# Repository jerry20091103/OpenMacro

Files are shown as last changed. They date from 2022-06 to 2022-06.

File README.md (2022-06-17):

# OpenMacro
A extensible macro device and password manager built with Arduino.

## About this repository

This repository contains three subprojects:
* **OpenMacro-Arduino:** A macropad program designed to be run on an Arduino Micro board.
* **OpenMacro-GUI:** A Qt application that can be used to configure an OpenMacro device. You will need the Arduino USB driver to detect the Arduino board.
* **OpenMacro-PCB:** A KiCad project that contains the layouts of a complete OpenMacro device.

Note that the OpenMacro-GUI project has a dependency to the OpenMacro-Arduino project's `Keycodes.h` and `MacroConfig.h`.

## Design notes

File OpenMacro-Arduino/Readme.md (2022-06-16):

# OpenMacro-Arduino

## Getting started with the source code
* Get the PlatfromIO extension in VScode.
* Click Open project in PlatformIO-home window and open the OpenMacro-Arduino folder.
* All libraries and tools should then automatically be installed.
* The Build and Upload button are in the bottom left corner.

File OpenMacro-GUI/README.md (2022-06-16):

# OpenMacro-GUI

## Getting started
* Open `CMakeLists.txt` in QtCreator, using the "Open Project" button. **Qt 6.3.0 is needed.**

## Debugging
* In the top menu bar, select debug options from the Debug menu.
    * These buttons are connected to slots in `App/debugmenu.h`.
    * For serial port testing, change the port name `debugPortName` defined in `App/debugmenu.cpp` to the name of the port your USB device is connected to.
* Remember that you can also see the console in Qt Creator!

## Project structure
* `App`: Contains GUI-related logic, as well as the `.ui` file that defines the UI layouts.
* `Core`: Contains OpenMacro data structures and functions.
* `commons.h`: Manages external includes.

## How to build the executable
* After building the CMake project from inside Qt Creator, you will need to add the following Qt `.dll` files to the folder containing `OpenMacro-GUI.exe`, which can be found under `Qt/6.3.0/mingw_64/bin`.
   * `libgcc_s_seh-1.dll`
   * `libstdc++-6.dll`
   * `libwinpthread-1.dll`
   * `Qt6Core.dll`
   * `Qt6Gui.dll`
   * `Qt6SerialPort.dll`
   * `Qt6Widgets.dll`
* You will also need to add `Qt/6.3.0/mingw_64/plugins/platforms` to the same folder.

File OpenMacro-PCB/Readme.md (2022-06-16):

# OpenMacro-PCB
* This folder contains Kicad 6 project files for OpenMacro.
* The electrical schematic and PCB layout Kicad files can be found here.

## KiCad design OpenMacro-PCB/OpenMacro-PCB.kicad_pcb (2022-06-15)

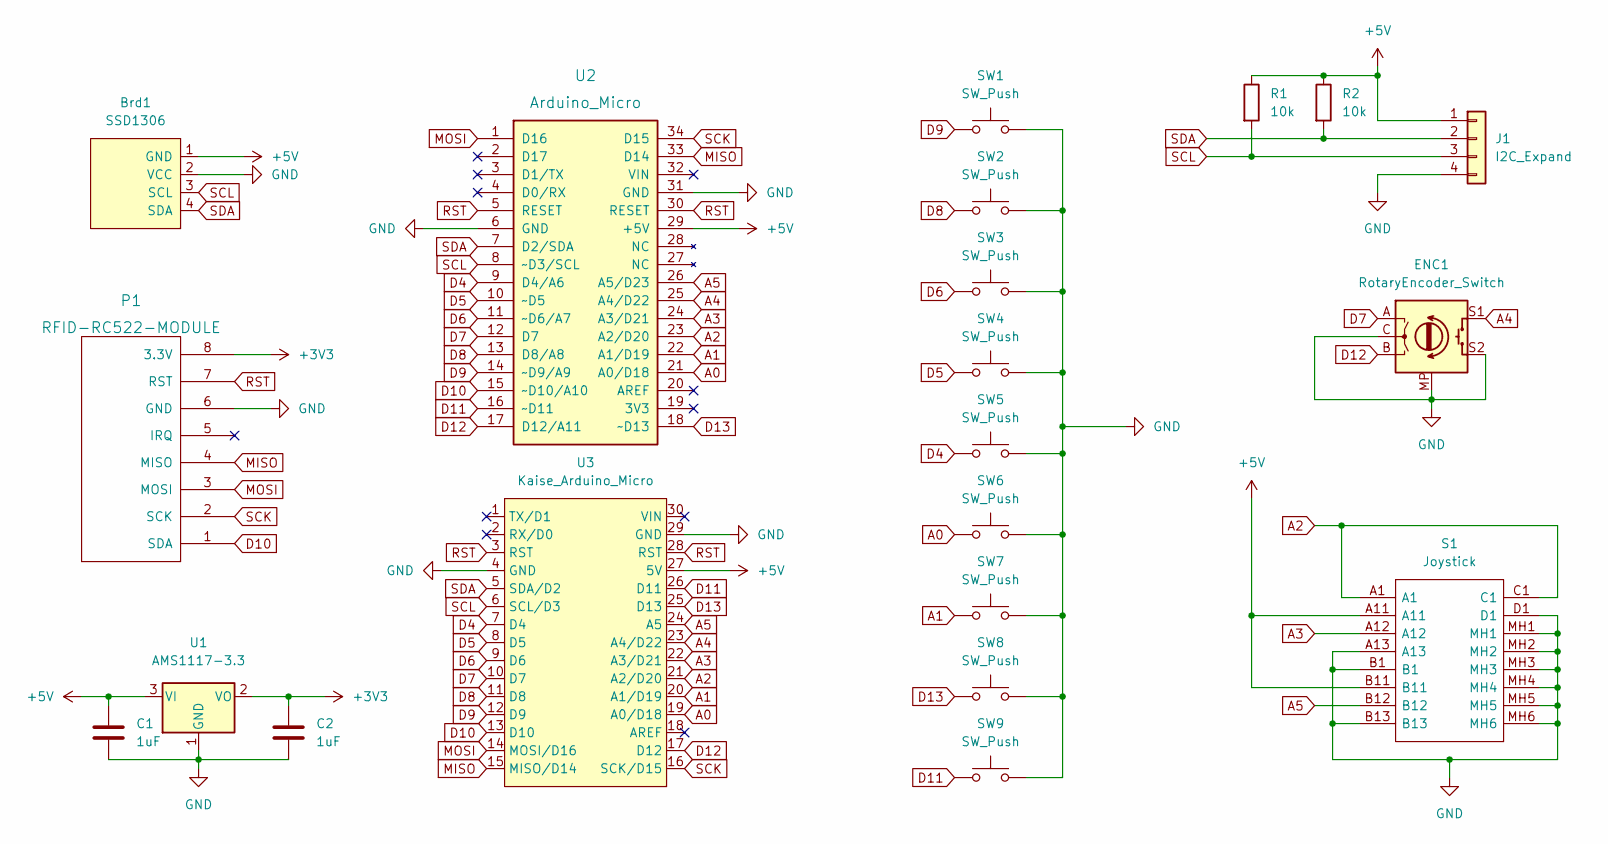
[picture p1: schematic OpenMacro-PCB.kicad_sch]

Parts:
Brd1: SSD1306; 128x64OLED
C1, C2: 1uF; C_1206_3216Metric_Pad1.33x1.80mm_HandSolder
ENC1: RotaryEncoder_Switch; RotaryEncoder_Alps_EC11E-Switch_Vertical_H20mm_CircularMoun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
J1: I2C_Expand; PinSocket_1x04_P2.54mm_Horizontal
P1: RFID-RC522-MODULE; RC-522-RFID
R1, R2: 10k; R_1206_3216Metric_Pad1.30x1.75mm_HandSolder
S1: Joystick; RKJXV122400R; Mouser Part Number 688-RKJXV122400R
SW1, SW2, SW3, SW4, SW5, SW6, SW7, SW8, SW9: SW_Push; MX-Alps-Choc-1U-NoLED
U1: AMS1117-3.3; SOT-223-3_TabPin2
U2: Arduino_Micro
U3: Kaise_Arduino_Micro

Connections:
+3V3: C2.1, P1.8 (3.3V), U1.2 (VO)
+5V: Brd1.1 (GND), C1.1, J1.1, R1.1, R2.1, S1.A11, S1.B11, U1.3 (VI), U2.29 (+5V), U3.27 (5V)
A0: SW6.1, U2.21 (A0/D18), U3.19 (A0/D18)
A1: SW7.1, U2.22 (A1/D19), U3.20 (A1/D19)
A2: S1.A1, S1.C1, U2.23 (A2/D20), U3.21 (A2/D20)
A3: S1.A12, U2.24 (A3/D21), U3.22 (A3/D21)
A4: ENC1.S1, U2.25 (A4/D22), U3.23 (A4/D22)
A5: S1.B12, U2.26 (A5/D23), U3.24 (A5)
D4: SW5.1, U2.9 (D4/A6), U3.7 (D4)
D5: SW4.1, U2.10 (~D5), U3.8 (D5)
D6: SW3.1, U2.11 (~D6/A7), U3.9 (D6)
D7: ENC1.A, U2.12 (D7), U3.10 (D7)
D8: SW2.1, U2.13 (D8/A8), U3.11 (D8)
D9: SW1.1, U2.14 (~D9/A9), U3.12 (D9)
D10: P1.1 (SDA), U2.15 (~D10/A10), U3.13 (D10)
D11: SW9.1, U2.16 (~D11), U3.26 (D11)
D12: ENC1.B, U2.17 (D12/A11), U3.17 (D12)
D13: SW8.1, U2.18 (~D13), U3.25 (D13)
GND: Brd1.2 (VCC), C1.2, C2.2, ENC1.C, ENC1.MP, ENC1.S2, J1.4, P1.6 (GND), S1.A13, S1.B1, S1.B13, S1.D1, S1.MH1, S1.MH2, S1.MH3, S1.MH4, S1.MH5, S1.MH6, SW1.2, SW2.2, SW3.2, SW4.2, SW5.2, SW6.2, SW7.2, SW8.2, SW9.2, U1.1 (GND), U2.6 (GND), U2.31 (GND), U3.4 (GND), U3.29 (GND)
MISO: P1.4 (MISO), U2.33 (D14), U3.15 (MISO/D14)
MOSI: P1.3 (MOSI), U2.1 (D16), U3.14 (MOSI/D16)
RST: P1.7 (RST), U2.5 (RESET), U2.30 (RESET), U3.3 (RST), U3.28 (RST)
SCK: P1.2 (SCK), U2.34 (D15), U3.16 (SCK/D15)
SCL: Brd1.3 (SCL), J1.3, R1.2, U2.8 (~D3/SCL), U3.6 (SCL/D3)
SDA: Brd1.4 (SDA), J1.2, R2.2, U2.7 (D2/SDA), U3.5 (SDA/D2)

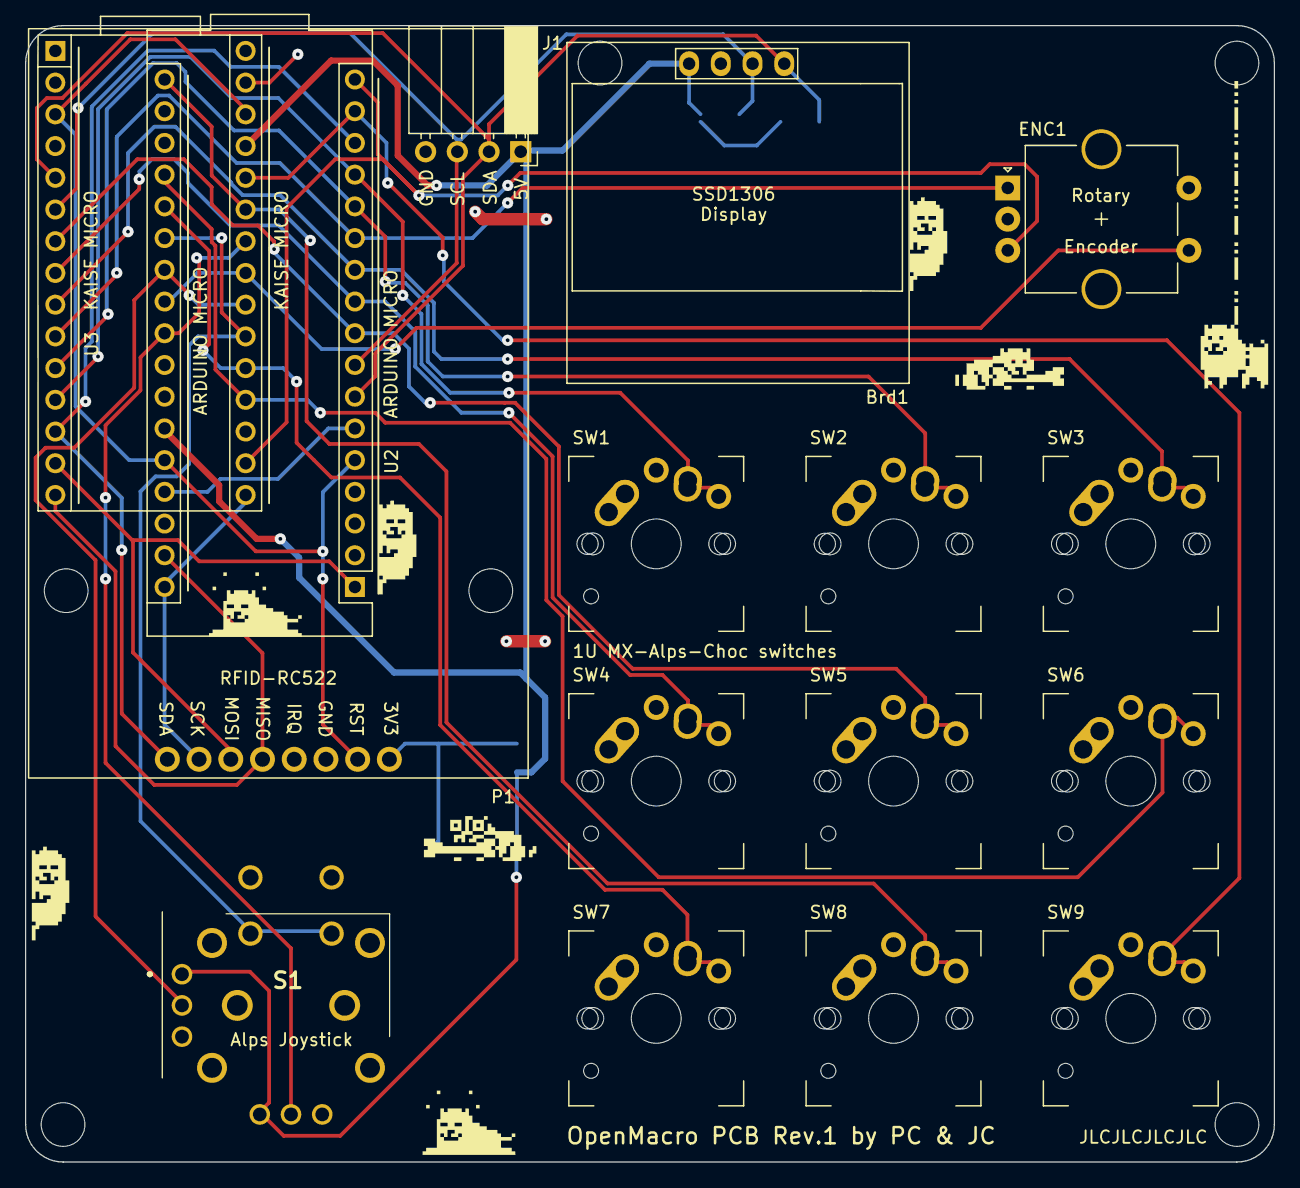
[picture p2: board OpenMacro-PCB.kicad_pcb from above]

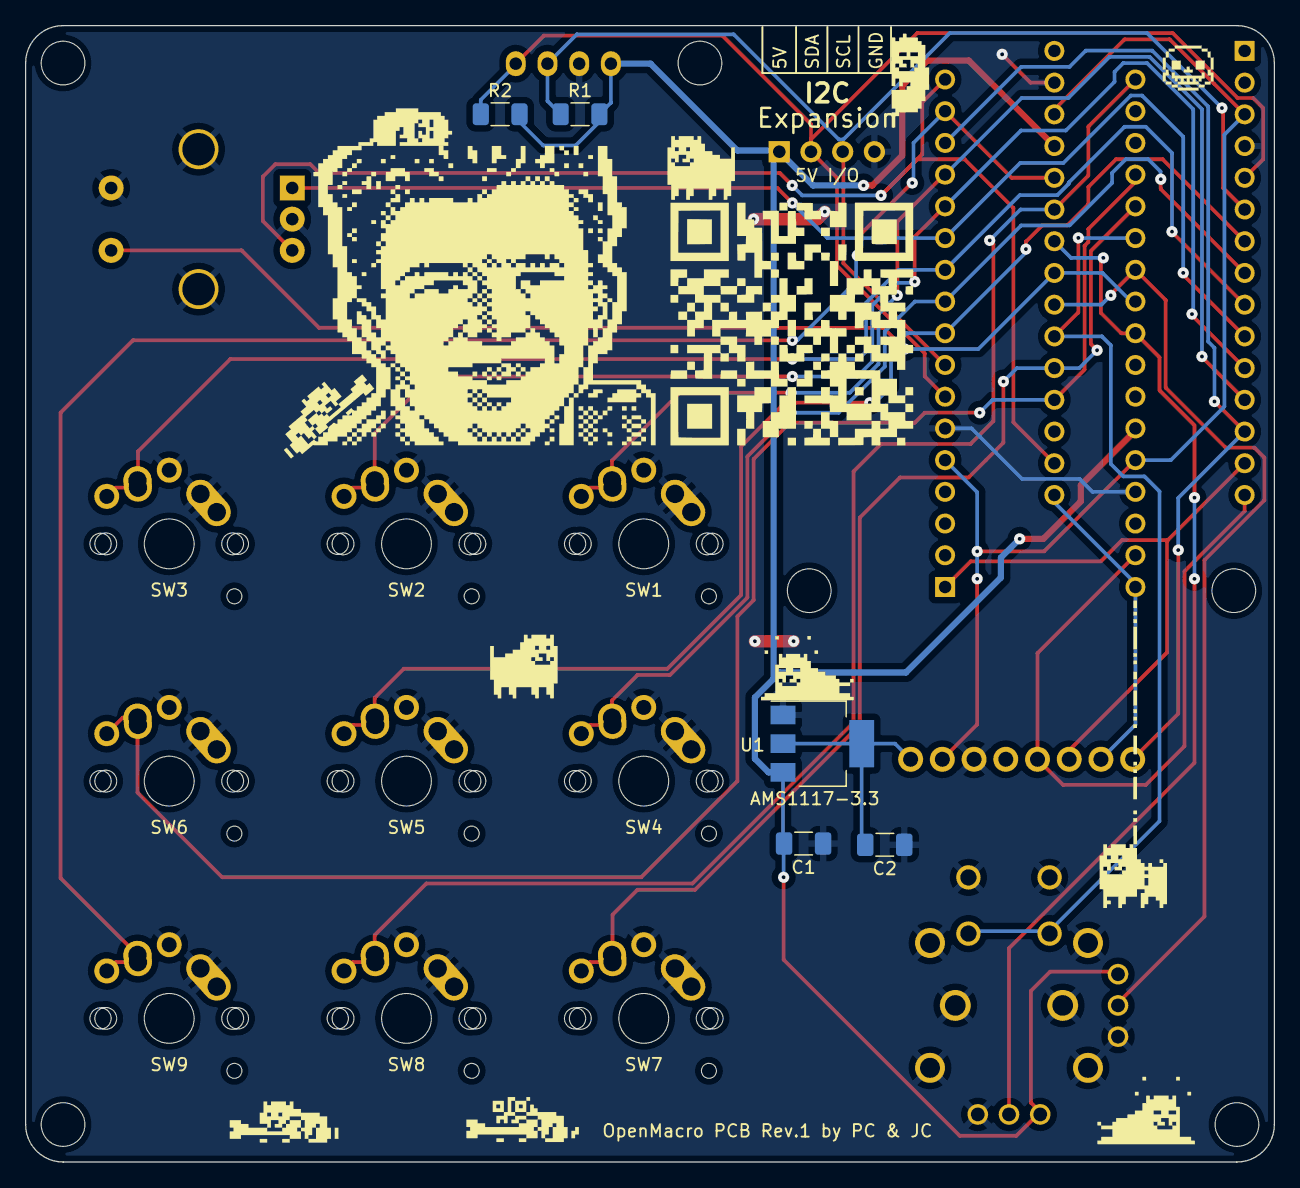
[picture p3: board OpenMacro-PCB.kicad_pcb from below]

Board: 2 copper layers, 100.0 x 91.0 mm, 21 parts (5 on the bottom side), 25 nets.

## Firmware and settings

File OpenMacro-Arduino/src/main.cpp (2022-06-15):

#include <Arduino.h>
#include "Hardware.h"
#include "Macros.h"
#include "AESLib.h"

/*
    *Libraries used:
    SSD1306Ascii by greiman  (display driver) https://github.com/greiman/SSD1306Ascii
    IoAbstraction by davetcc (scheduling, buttons, encoders, IO expansion)  https://www.thecoderscorner.com/products/arduino-libraries/io-abstraction/
    MFRC522 by miguelbalboa  (RFID driver)
    HID-Project by NicoHood  (extends functionality of Arduino HID library)
    AESLib by davylandman    (AES password encryption)
*/

void receiveSerial_readAnalog()
{
    if (Serial && Serial.available())
    {
        oled.clear();
        oled.print(F("RECEIVING")); // the "F()" stuff around the string means we store the string in flash instead of SRAM

        if (macros.readFromSerial())
        {
            if (macros.config.isPassword)
            {
                if (macros.readRfid())
                {
                    uint8_t key[16];
                    for (uint8_t i = 0; i < 16; i++)
                    {
                        key[i] = macros.rfidUID[i % 4];
                    }
                    // encrypt password with UID
                    for (uint8_t i = 0; i < MAX_PASSWORDS; i++)
                    {
                        aes128_enc_single(key, macros.config.passwordConfig.passwords[i].str);
                    }
                    macros.saveToEEPROM(true);
                    oled.setCol(0);
                    oled.print(F("PASSWORD\nRECEIVED"));
                }
                else
                {
                    oled.setCol(0);
                    oled.print(F("RFID\nTIMEOUT"));
                }
                // read back macros
                macros.readFromEEPROM(false);
                taskManager.scheduleOnce(5000, displayCurMode);
            }
            else
            {
                macros.saveToEEPROM(false);
                oled.clear();
                oled.print(F("MACRO\nRECEIVED"));
                // open 1200 magic baud to let GUI force reset
                Serial.begin(1200);
            }
        }
        else
        {
            oled.clear();
            oled.print(F("ERROR")); // the "@" here means space, cause we are using custom font to save space
            // roll back contents from eeprom
            if (!macros.readFromEEPROM(false))
            {
                macros.clearConfig();
            }
        }
        taskManager.scheduleOnce(5000, displayCurMode);
    }

    Gamepad.xAxis(map(analogRead(JOY_X), 1024, 0, INT16_MIN, INT16_MAX));
    Gamepad.yAxis(map(analogRead(JOY_Y), 1024, 0, INT16_MIN, INT16_MAX));
    Gamepad.write();
}

void setup()
{
    Serial.begin(9600);
    HardwareSetup();

    taskManager.scheduleFixedRate(5, receiveSerial_readAnalog);

    if (!macros.readFromEEPROM(false))
    {
        oled.print(F("NO@MACRO"));
    }
    else
    {
        oled.print(F("WELCOME"));
        uint8_t expanded = 0;
        if (expanded = macros.setupMacros())
        {
            //oled.setCursor(0, 3);
            oled.print(F("\nEXPANDER"));
            oled.print(expanded);
        }
    }
    taskManager.scheduleOnce(5000, displayCurMode);
}

void loop()
{
    taskManager.runLoop();
}

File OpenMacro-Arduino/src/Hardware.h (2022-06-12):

#ifndef HARDWARE_H
#define HARDWARE_H

#include "IoAbstractionWire.h"
#include "TaskManagerIO.h"
#include "MFRC522.h"
#include "SSD1306Ascii.h"
#include "SSD1306AsciiWire.h"
#include "HID-Project.h"
#include <EEPROM.h>
#include <Wire.h>

// *Pins
// Rotray Encoders and buttons
#define ENCA 7
#define ENCB 12
#define BTN_ENC_PIN 22

// buttons
#define BTN0_PIN 9
#define BTN1_PIN 8
#define BTN2_PIN 6
#define BTN3_PIN 5
#define BTN4_PIN 4
#define BTN5_PIN 18
#define BTN6_PIN 19
#define BTN7_PIN 13
#define BTN8_PIN 11

// joysticks
#define JOY_X A5
#define JOY_Y A3
#define BTN_JOY_PIN 20

// rfid
#define RFID_SS 10
#define RFID_RST 17

// display
#define DISPLAY_ADD 0x3c

// expanders
#define EXPANDER_PIN_OFFSET 30 
// *pin numbers starting from 30 are external pins from expanders.

// rotary encoder object
extern HardwareRotaryEncoder* enc0;

// RFID reader object
extern MFRC522 rfid;

// OLED display object
extern SSD1306AsciiWire oled;

extern MultiIoAbstractionRef multiIo;

void HardwareSetup();

#endif

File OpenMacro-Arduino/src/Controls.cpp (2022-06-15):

#include "Controls.h"
#include "Macros.h"
#include "TaskManagerIO.h"
#include "ExecWithParameter.h"

void runMacroTask(uint8_t input)
{
    macros.runMacro(input);
}

void BtnPressCallback(pinid_t pin, bool isHeld)
{
    // we put serial here for testing
    // Serial.print(F("Button Press:"));
    // Serial.println(pin);

    // !DEBUG
    // hold BTN1 to print config to serial
    // if (pin == BTN1_PIN && isHeld)
    // {
    //     macros.dumpConfig();
    // }
    if (pin == BTN_ENC_PIN && isHeld)
    {
        oled.clear();
        oled.print(F("UPLOAD\nMACRO"));
        if(!macros.sendToSerial())
        {
            oled.clear();
            oled.print(F("ERROR"));
        }
        taskManager.scheduleOnce(5000, displayCurMode);
    }
    else if (!isHeld)
    {
        auto task = new ExecWithParameter<uint8_t>(runMacroTask, getInputPinNum(pin));
        taskManager.execute(task, true);
    }
}

void BtnReleaseCallback(pinid_t pin, bool isHeld)
{
    if(pin == BTN_ENC_PIN && !isHeld)
    {
        macros.passwordMode = !macros.passwordMode;
        if (macros.passwordMode && !macros.readRfid())
        {
            macros.passwordMode = false;
            oled.setCol(0);
            oled.print(F("RFID\nTIMEOUT"));
            taskManager.scheduleOnce(5000, displayCurMode);
        }
        else
        {
            displayCurMode();
        }
    }
    else if(pin == BTN_JOY_PIN)
    {
        macros.releaseMacro(getInputPinNum(pin));
    }
}

void EncCallback(int value)
{
    // Serial.print(F("Encoder:"));
    // Serial.println(value);

    if (value > 0)
    {
        macros.runMacro(ENC_DEC);
    }
    else if (value < 0)
    {
        macros.runMacro(ENC_INC);
    }
}

// convert pin number to input number
uint8_t getInputPinNum(uint8_t hardwarePin)
{
    // expanded pins
    if (hardwarePin >= EXPANDER_PIN_OFFSET)
    {
        return hardwarePin - EXPANDER_PIN_OFFSET + NUM_BTN_INPUTS;
    }
    // internal pins
    else
    {
        switch (hardwarePin)
        {
        case BTN0_PIN:
            return 0;
            break;
        case BTN1_PIN:
            return 1;
            break;
        case BTN2_PIN:
            return 2;
            break;
        case BTN3_PIN:
            return 3;
            break;
        case BTN4_PIN:
            return 4;
            break;
        case BTN5_PIN:
            return 5;
            break;
        case BTN6_PIN:
            return 6;
            break;
        case BTN7_PIN:
            return 7;
            break;
        case BTN8_PIN:
            return 8;
            break;
        case BTN_JOY_PIN:
            return BTN_JOY;
            break;

        default:
            return 200;
            break;
        }
    }
}

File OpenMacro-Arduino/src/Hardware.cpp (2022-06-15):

#include "Hardware.h"
#include "Controls.h"
#include "font5x7_u.h"

HardwareRotaryEncoder *enc0;
MFRC522 rfid;
SSD1306AsciiWire oled;

// io abstraction object
MultiIoAbstractionRef multiIo = multiIoExpander(EXPANDER_PIN_OFFSET);

void HardwareSetup()
{
    Wire.begin();
    // We use IOAbstraction library to handle switches and rotary encoders.
    // It also has built task manager for easy scheduling.
    // With the help of this library, we can also add IO pins with I2C expanders and can use them as if they were original arduino pins.
    // https://www.thecoderscorner.com/products/arduino-libraries/io-abstraction/
    switches.init(multiIo, SWITCHES_POLL_KEYS_ONLY, true);
    //* setup rotray encoder
    enc0 = new HardwareRotaryEncoder(ENCA, ENCB, EncCallback, HWACCEL_SLOWER);
    // add encoder to the switches object in the library
    switches.setEncoder(0, enc0);
    // set how the encoders operate
    enc0->changePrecision(0, 0);
    //* setup buttons
    switches.addSwitch(BTN_ENC_PIN, BtnPressCallback);
    switches.addSwitch(BTN_JOY_PIN, BtnPressCallback);
    switches.addSwitch(BTN0_PIN, BtnPressCallback);
    switches.addSwitch(BTN1_PIN, BtnPressCallback);
    switches.addSwitch(BTN2_PIN, BtnPressCallback);
    switches.addSwitch(BTN3_PIN, BtnPressCallback);
    switches.addSwitch(BTN4_PIN, BtnPressCallback);
    switches.addSwitch(BTN5_PIN, BtnPressCallback);
    switches.addSwitch(BTN6_PIN, BtnPressCallback);
    switches.addSwitch(BTN7_PIN, BtnPressCallback);
    switches.addSwitch(BTN8_PIN, BtnPressCallback);
    switches.onRelease(BTN_ENC_PIN, BtnReleaseCallback);
    switches.onRelease(BTN_JOY_PIN, BtnReleaseCallback);
    // multiIoAddExpander(multiIo, ioFrom23017(0x20), 16);
    // switches.addSwitch(EXPANDER_PIN_OFFSET, BtnPressCallback);
    // switches.addSwitch(EXPANDER_PIN_OFFSET + 1, BtnPressCallback);
    // switches.addSwitch(EXPANDER_PIN_OFFSET + 2, BtnPressCallback);
    // switches.addSwitch(EXPANDER_PIN_OFFSET + 3, BtnPressCallback);

    //* setup display
    oled.begin(&Adafruit128x64, DISPLAY_ADD);
    oled.setFont(font5x7_u); // this is a custom font with only numbbers and UPPER case characters, use "@" for space
    oled.set2X();
    oled.clear();

    //* setup RFID
    SPI.begin();
    rfid.PCD_Init(RFID_SS, RFID_RST);

    //*  start keyboard library
    Keyboard.begin();
    Mouse.begin();
    Gamepad.begin();
    Consumer.begin();
}

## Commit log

2022-05-14 Add key matrix, change display driver to text only
2022-05-21 Renamed preset buttons.
2022-05-21 Remove button matrix, change HID library.
2022-05-21 remove MacroConfig's depedency on arduino stuff.
2022-05-21 Added InputList class and hooked up slots
2022-05-25 Add Kicad PCB project files.
    [OpenMacro-PCB.kicad_pcb, OpenMacro-PCB.kicad_sch]
2022-05-30 Update kicad_sch.
    [OpenMacro-PCB.kicad_sch]
2022-05-30 Update kicad_pcb.
    [OpenMacro-PCB.kicad_pcb]
2022-06-05 Added Connect to Device function.
2022-06-05 Fixed crash when switching inputs
2022-06-06 Unregistered timer during IO
2022-06-06 Set timerId to -1
2022-06-09 Serial receive working. Macros still have problems
    [OpenMacro-PCB.kicad_pcb]
2022-06-11 Fix force reset bug, add basic password support.
    [Controls.cpp, Hardware.cpp, Macros.cpp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]
2022-06-12 Switch to even smaller display driver; Add AES.
2022-06-14 Password working, downloading does not work.
    [Controls.cpp, Hardware.cpp, Macros.cpp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]
2022-06-14 Fix bug in download serial.
    [Controls.cpp, Macros.cpp]
2022-06-14 Add port filtering; reduce some flash usage.
2022-06-14 Add AES password encryption; fix memory issues
    [Macros.cpp, main.cpp]
2022-06-15 Add long press to joystick button
2022-06-15 Fix bug in PCB.
    [OpenMacro-PCB.kicad_pcb, OpenMacro-PCB.kicad_sch]
2022-06-16 Update readme.md in OpenMacro-Arduino
2022-06-16 Update Readme.md in OpenMacro-PCB.
